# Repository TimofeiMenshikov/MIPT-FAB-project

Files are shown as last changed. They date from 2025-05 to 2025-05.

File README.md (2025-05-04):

# Пояснительная записка к учебному проекту "СТАНЦИЯ МОНИТОРИНГА МИКРОКЛИМАТА" по курсу "Практикум по цифровому производству"

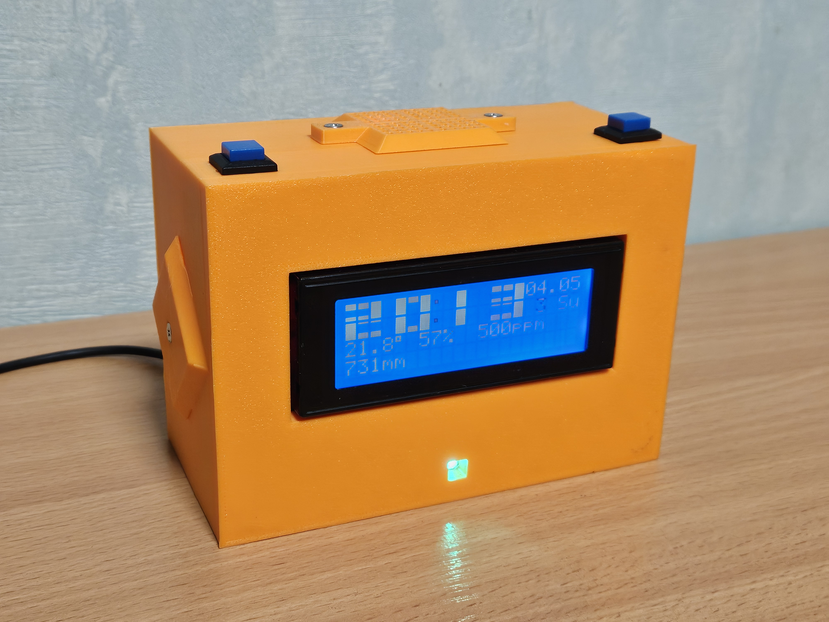
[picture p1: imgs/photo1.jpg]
общее фото станции


## Авторы проекта

- Сапунов Филипп ([@Feanor19](https://t.me/Feanor19)) - проектирование корпуса, пайка, сборка устройства
- Меньшиков Тимофей ([@tifomei](https://t.me/tifomei)) - код прошивки и всё с ним связанное

## Причины выбора темы

В комнате в общежитии понадобилось наблюдать примерный уровень углекислого газа и температуру воздуха, чтобы эффективнее проветривать помещение (особенно в холодное время года).

## Первичные требования к проекту

### Измеряемые показатели

1. Температура окружающего воздуха;
2. Влажность окружающего воздуха;
3. Атмосферное давление;
4. Уровень углекислого газа (ppm).

### Отображаемая информация

1. Время и дата (при отключении питания не должны отставать от реального);
2. Температура, влажность, давление, углекислый газ (показания с датчиков в данный момент времени);
3. Графики показаний с перечисленных выше датчиков за сутки.

### Общие требования

1. Изменение яркости дисплея в соответствии с освещённостью вокруг (когда в комнате выключен свет, дисплей не должен ярко гореть);
2. Светодиод, отражающий регистрируемый уровень углекислого газа (зелёный, когда показания в норме, красный и мигающий красный при превышении нормы);
3. Удобный интерфейс, управляемый несколькими механическими кнопками. Множество режимов отображения, лёгкое переключение между ними. Настройка режима яркости дисплея и светодиода, выставление времени.
4. Питание должно быть возможно от обычного блока питания на 5В (как для смартфона), разъём USB Type-C или micro-USB.

## Первичные поставленные задачи

1. Выбор электронных компонентов
2. Прототипирование на макетной плате, проверка компонентов
3. Составление блок-схемы интерфейса
4. Проектирование схемы соединения компонентов
5. Проектирование моделей корпуса
6. Разработка и тестирование прошивки на макетной плате
7. Сборка и проверка работоспособности

## Процесс решения поставленных задач

Здесь кратко описан процесс решения поставленных задач. Некоторые принятые по началу решения изменялись в дальнейшем; здесь всё представлено в хронологической последовательности. Чтобы узнать финальную версию, см. [здесь](#финальная-версия)

### Выбор электроники (первая версия)

В соответствии с заданными требованиями были подобраны следующие компоненты:

1. Arduino Nano;
2. Датчик температуры, влажности, давления BME280;
3. Датчик углекислого газа MH-Z19B;
4. Большой символьный дисплей LCD 2004 I2C;
5. RTC (часы реального времени) DS3231 mini;
6. Механические кнопки;
7. Фоторезистор;
8. RGB LED модуль;
9. Разъём питания USB Type-C.

### Первая версия блок-схемы интерфейса

В соответствии с заданными требованиями была составлена блок-схема интерфейса с использованием двух кнопок.

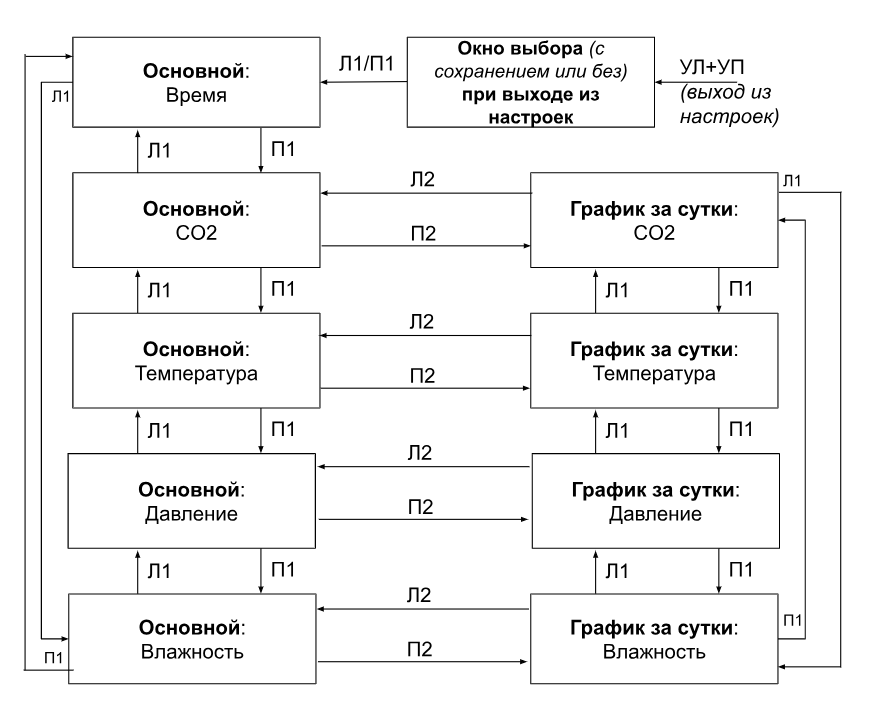
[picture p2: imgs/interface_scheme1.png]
блок-схема интерфейса 1


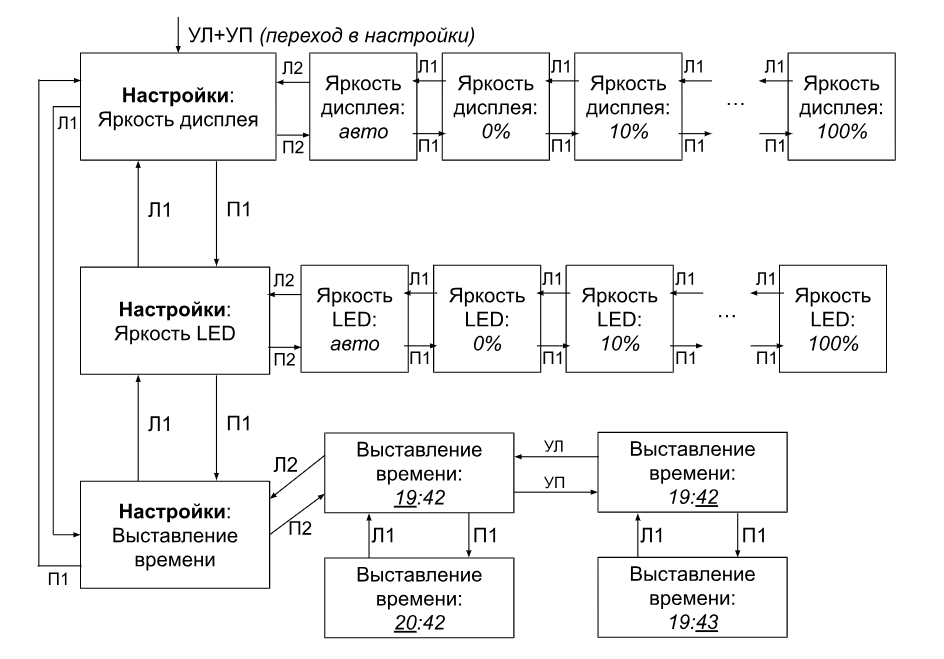
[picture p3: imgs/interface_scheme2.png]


Обозначения:

- Л1 – одиночное нажатие левой кнопки
- П1 – одиночное нажатие правой кнопки
- Л2 – двойное нажатие левой кнопки
- П2 – двойное нажатие правой кнопки
- УЛ – длительное удержание левой кнопки
- УП – длительное удержание правой кнопки

В основном режиме отображается один показатель увеличено, остальные – в уменьшенном и сокращённом виде. УЛ+УП (одновременное длительное нажатие левой и правой кнопки) из любого экрана переводит в режим настроек, и из любого экрана настроек переводит в основной через окно с подтверждением сохранения изменений.

### Прототипирование на макетной плате и начало разработки прошивки

Для отлаживания прошивки в процессе её разработки требовались все компоненты, подключенные к макетной плате (breadboard), и возможность легко подключать/отключать их к разным пинам ардуино. Кроме того, ещё не была утверждена финальная схема соединения компонентов, т.к. во время разработки прошивки могли выясниться какие-то нюансы, требующие её модификации. По этим причинам уже на этом этапе к кнопкам и датчику CO2 были припаяны половинки джамперов папа-папа, чтобы обеспечить их легкое подключение к макетной плате. Джамперов мама-папа на тот момент в наличии не было, а паяльник был ещё горячий, поэтому половинки джамперов папа-папа были заодно припаяны к пинам дисплея (геометрия пинов не позволяла втыкать их в макетную плату напрямую).

В ходе разработки прошивки выяснилось, что отлавливать раздельно события "УЛ" и "УП" при наличии события "УЛ+УП" неоправданно сложно. Поэтому часть интерфейса, отвечающая за выставление времени в настройках, была изменена: переход между выставлением часов и выставлением минут совершается путём срабатывания "П1", а выставление числа часов/минут совершается путём срабатывания "Л1" (число увеличивается на единицу).

### Первая версия схемы соединения компонентов

Через некоторое время после начала разработки прошивки появилось понимание, как должна выглядеть схема соединения компонентов. По итогу была спроектирована и утверждена следующая схема:

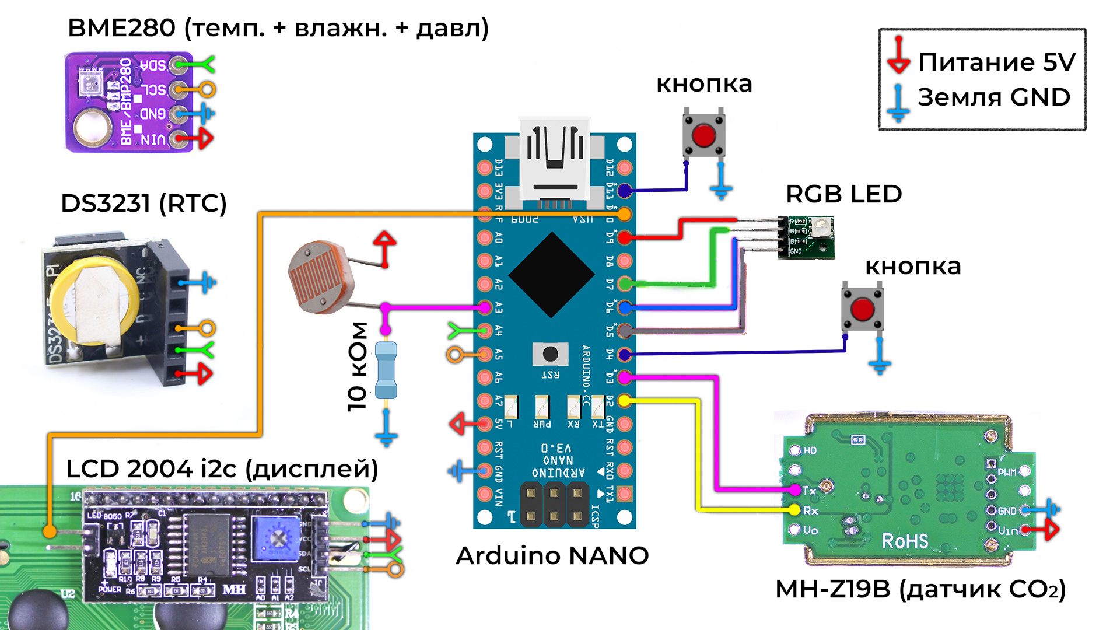
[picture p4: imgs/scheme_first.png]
схема соединения


Датчик BME280, RTC и дисплей подключены на общую шину I2C. На схеме не показан порт питания, в него должен вставляться провод от обычного блока питания на 5В (как для смартфонов).

### Проектирование корпуса

Все файлы были сделаны в SOLIDWORKS 2020, расположены [тут](models/).

Были созданы макеты компонентов (названия начинаются с "mock_") для проверки в виртуальной сборке. Для крепления было решено использовать впаиваемые гайки (aka резьбовые втулки) и винты. Для крепления двух половинок корпуса ([передняя](models/case_front.SLDPRT) и [задняя](models/case_back.SLDPRT)) используются потайные М3 винты (чтобы были вровень с поверхностью, закрывать их какой-то нашлепкой не предполагается). Также М3 винтами, вкручиваемыми снаружи, крепятся датчик BME и разъём питания, закрепляясь изнутри обычной гайкой.

В ходе разработки корпуса и продумывания крепления компонентов выяснилось, что выбранный разъём питания USB Type-C не имеет удобных отверстий для крепления, в отличие от разъёма питания micro-USB из личных запасов, который и был в итоге выбран.

Датчику BME требуется доступ к воздуху в комнате, для этих целей на [задней грани](models/case_back.SLDPRT) предусмотрено квадратное отверстие размером чуть больше чувствительной части датчика.

Датчику CO2 тоже требуется доступ к воздуху в комнате, для этого сделана решётка в виде отдельной [детали](models/case_grid.SLDPRT), накрывающая датчик сверху. К задней половине корпуса она крепится потайными М3 винтами, которые вкручиваются в ответные впаиваемые гайки. Сам датчик помещается на сделанную для него "полочку", фиксирующую его положение по двум осям; соединение половин корпуса фиксирует его положение и по третьей оси.

Под фоторезистор отдельное отверстие не предусмотрено, вместо этого оставлена достаточно широкая щель по краям дисплея, с обратной стороны которой предполагается закреплять фоторезистор (специальное крепление не предусмотрено).

#### Подгонка размеров

Отверстия под впаиваемые гайки должны были быть нужного размера, чтобы те в них хорошо закреплялись. При этом при 3D-печати размеры могут значительно искажаться. Поэтому были созданы тестовые модельки (их названия начинаются с "test_suite"), в которых были сделаны отверстия под М2 и М3 впаиваемые гайки, а также под потайные винты М3, использующиеся в нескольких местах корпуса. Во второй [тестовой модельке](models/test_suite_potay.SLDPRT) заодно была протестирована печать "крепёжного уха" в том же положении, в котором оно печаталось как часть передней половинки корпуса.

Тестовые модельки печатались из PLA, из него же печатались и финальные модели.

Первая тестовая моделька претерпела несколько итераций печати и сверки, пока не был подобран нужный размер.

### Продолжение разработки прошивки

В ходе продолжения разработки прошивки выяснилось, что требуется немного изменить подключение светодиода. Пин G светодиода был подключен в пин ардуино D7, не поддерживающий ШИМ. Из-за этого когда светодиод светился зеленым, его яркостью нельзя было управлять (это было упущено по началу, т.к. проверка изменения яркости проводилась при свечении красным). Модификацию схемы подключения см. [здесь](#финальная-версия)

### Сборка

К моменту, когда было пора паять схему, пришла идея вместо этого собрать все на джамперах, получив таким образом полностью разборную конструкцию, позволяющую легко заменить любой компонент, даже без перепаивания. Для этих целей из найденных в личных запасах "ног" были спаяны 4 шины: земля, питание и две шины для I2C.

Первая собранная и уложенная в корпус схема выглядела так:

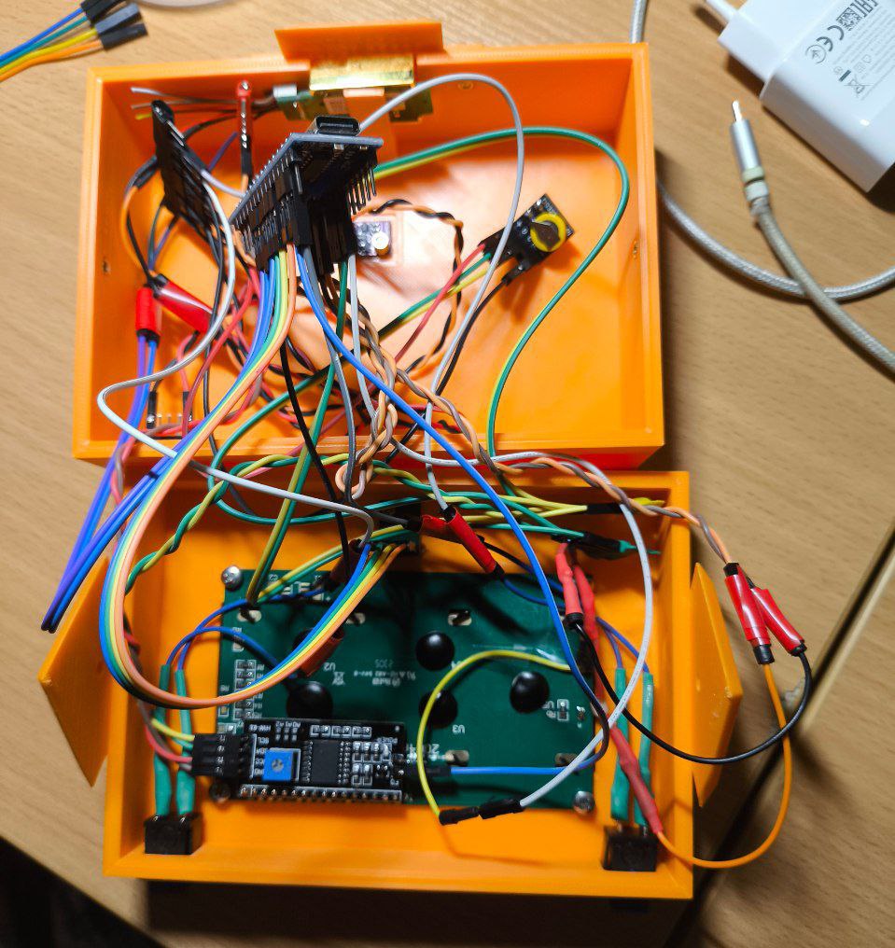
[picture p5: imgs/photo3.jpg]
Первая версия сборки


И она, конечно, не заработала. Только часть компонентов были надежно прикреплены к корпусу (дисплей, RGB LED, датчик BME, датчик CO2), остальные (ардуино, RTC, все четыре шины...) свободно перемещались внутри, вызывая отсоединение одних контактов и появление незапланированных других.

После этого схема была целиком разобрана и собрана заново:

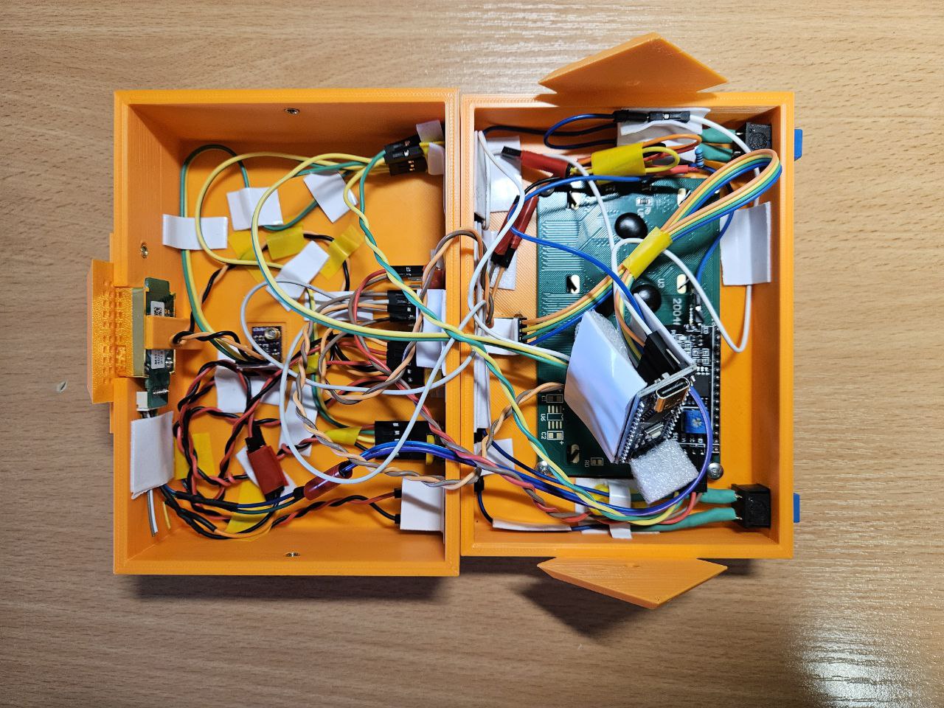
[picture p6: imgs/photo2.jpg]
Вторая версия сборки


На этот раз все провода прикреплялись к стенкам двусторонним скотчем, все соединения прозванивались. Выяснилось, что левая кнопка работала только при определенном положении припаянных к ней проводов, поэтому они тоже были надёжно зафиксированы c помощью подручных средств. Стоит заметить, что обильное использование двустороннего скотча не нарушает разборность конструкции и не мешает при надобности заменять отдельные компоненты, т.к. он снимается без следа.

### Проблемы и их решения после сборки

Казалось бы, станция была собрана и полностью работала, откуда взяться проблемам?

**Проблема №1**:

Один из авторов захотел попробовать запитать станцию от умного блока питания, способного выдавать различные мощности в зависимости от типа подключенного устройства. После этого эксперимента ардуино не работало при питании через внешний порт; вероятно, сгорел стабилизатор питания на входе 5V.

**Решение:**

Была получена новая ардуино и, благодаря разборности схемы, легко и без пайки подключена вместо старой.

**Проблема №2**:

Через некоторое время после использования станции отвалилось гнездо на плате питания.

**Решение:**

К новой такой же плате были припаяны ноги, плата была подключена вместо старой. Разборность схемы снова немного упростила замену сломанных компонентов.

## Финальная версия

### Компоненты

1. Arduino Nano;
2. Датчик температуры, влажности, давления BME280;
3. Датчик углекислого газа MH-Z19B;
4. Большой символьный дисплей LCD 2004 I2C;
5. RTC (часы реального времени) DS3231 mini;
6. Две механические кнопки;
7. Фоторезистор и резистор 10кОм;
8. RGB LED модуль;
9. Разъём питания micro-USB.

_Изменения по сравнению с первой версией:_

Изменён разъём питания из-за отсутствия возможности крепежа первого.

### Схема соединения компонентов

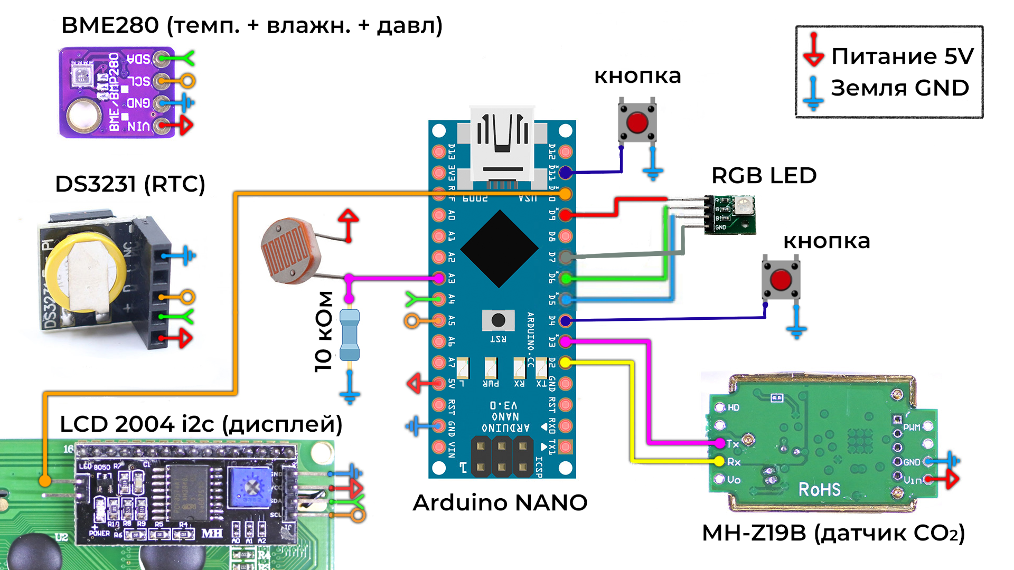
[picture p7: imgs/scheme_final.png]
схема


_Изменения по сравнению с первой версией:_

Изменено подключение пинов светодиодного модуля.

### Блок-схема интерфейса

блок-схема интерфейса 1

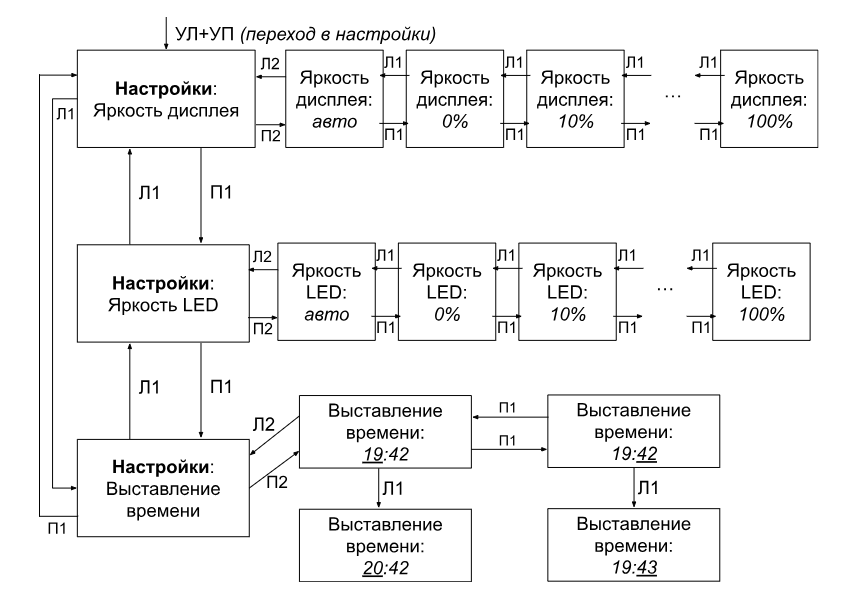
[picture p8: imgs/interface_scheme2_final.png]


_Изменения по сравнению с первой версией:_

Изменена только вторая часть интерфейса: убраны события "УЛ" и "УП", которые использовались только в выставлении времени.

### Модели для 3D-печати

Все модели расположены в директории [models](/models).

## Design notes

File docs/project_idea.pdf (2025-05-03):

Команда: Сапунов Филипп sapunov.fv@phystech.edu, Меньшиков Тимофей

Цель проекта: спроектировать и изготовить компактную станцию, измеряющую несколько параметров воздуха в комнате (температура, влажность, свежесть), уведомляющую о значительном ухудшении качества воздуха и отображающую полученные измерения несколькими удобными способами.

Задачи проекта: выбор доступной элементной базы; написание кода для первого прототипа и сборка схемы на макетной плате; проектирование и изготовление корпуса; доработка кода для увеличения количества режимов отображения и обработки собираемой с датчиков информации; сверка показаний датчиков в течение продолжительного периода времени с коммерческим решением.

Существующие аналоги:

1. Часы-метеостанция на Arduino своими руками - AlexGyver Technologies (https://alexgyver.ru/meteoclock/?ysclid=m6q3mdb4qh222157203) -открытое решение. Имеет несколько небольших недостатков (неудобство управления, слабая защита питания), которые планируется исправить в предлагаемом проекте, помимо дополнения новыми функциями.
2. Монитор качества воздуха с AliExpress (https://aliexpress.ru/item/1005007847792846.html?sku_id=12000042521033746) - один из множества вариантов, наиболее близкий по планируемому функционалу.
3. LIFAair LA352 - Система домашней очистки воздуха (https://lifarussia.ru/product/la352/) - включает в себя, помимо самого устройства очистки, монитор-контроллер качества воздуха. Имеется потенциальная возможность сверить показания этого устройства с результатом проекта (см. последний пункт задач проекта), учитывая при выводах значительную разницу ценовых категорий.

Подробный анализ аналогов будет представлен в итоговом отчете.

Эскиз: (итоговый дизайн может отличаться)

# Предложение проекта: станция мониторинга микроклимата

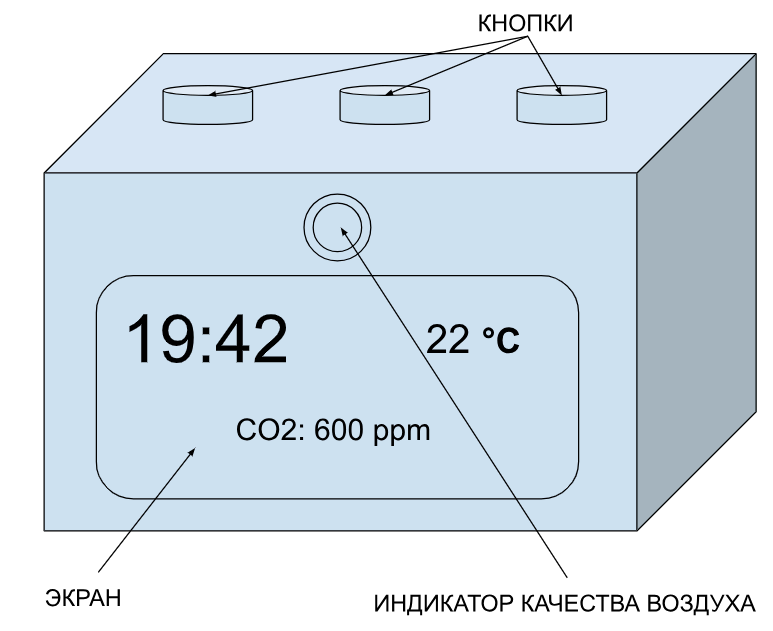
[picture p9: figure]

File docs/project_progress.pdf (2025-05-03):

# ПРЕЗЕНТАЦИЯ ПРОГРЕССА ПО ПРОЕКТУ «СТАНЦИЯ МОНИТОРИНГА МИКРОКЛИМАТА»

I. Были подробно сформулированы и утверждены требования к проекту:
1. Измеряемые показатели:
a. Температура окружающего воздуха (точность ±1 ºC);
b. Влажность окружающего воздуха;
c. Атмосферное давление;
d. Уровень углекислого газа (ppm).
2. Отображаемая информация:
a. Время и дата (при отключении питания не должны отставать от реального);
b. Температура, влажность, давление, углекислый газ (показания с датчиков в данный момент времени);
c. Графики показаний с перечисленных выше датчиков за сутки.
3. Общие требования:
a. Изменение яркости дисплея в соответствии с освещѐнностью вокруг (когда в комнате выключен свет, дисплей не должен ярко гореть);
b. Светодиод, отражающий регистрируемый уровень углекислого газа (зелѐный, когда показания в норме, красный и мигающий красный при превышении нормы);
c. Удобный интерфейс, управляемый несколькими механическими кнопками. Множество режимов отображения, лѐгкое переключение между ними. Настройка режима яркости дисплея и светодиода, выставление времени.
d. Питание должно быть возможно от обычного блока питания на 5В (как для смартфона), разъѐм USB Type-C или micro-USB.

II. В соответствии с заданными требованиями были подобраны следующие компоненты:

1. Arduino Nano;
2. Датчик температуры, влажности, давления BME280;
3. Датчик углекислого газа MH-Z19B;
4. Большой символьный дисплей LCD 2004 I2C;
5. RTC (часы реального времени) DS3231 mini;
6. Механические кнопки (из личных запасов, выбор конкретных позже);
7. Фоторезистор;
8. RGB LED модуль;
9. Разъѐм питания USB Type-C;
10. В личных запасах были макетная плата (breadboard) и набор проводов (jump wire) для сборки прототипа.

III. В соответствии с заданными требованиями был составлен план интерфейса с использованием двух механических кнопок:

- Л1 – одиночное нажатие левой кнопки
- П1 – одиночное нажатие правой кнопки
- Л2 – двойное нажатие левой кнопки
- П2 – двойное нажатие правой кнопки
- УЛ – длительное удержание левой кнопки

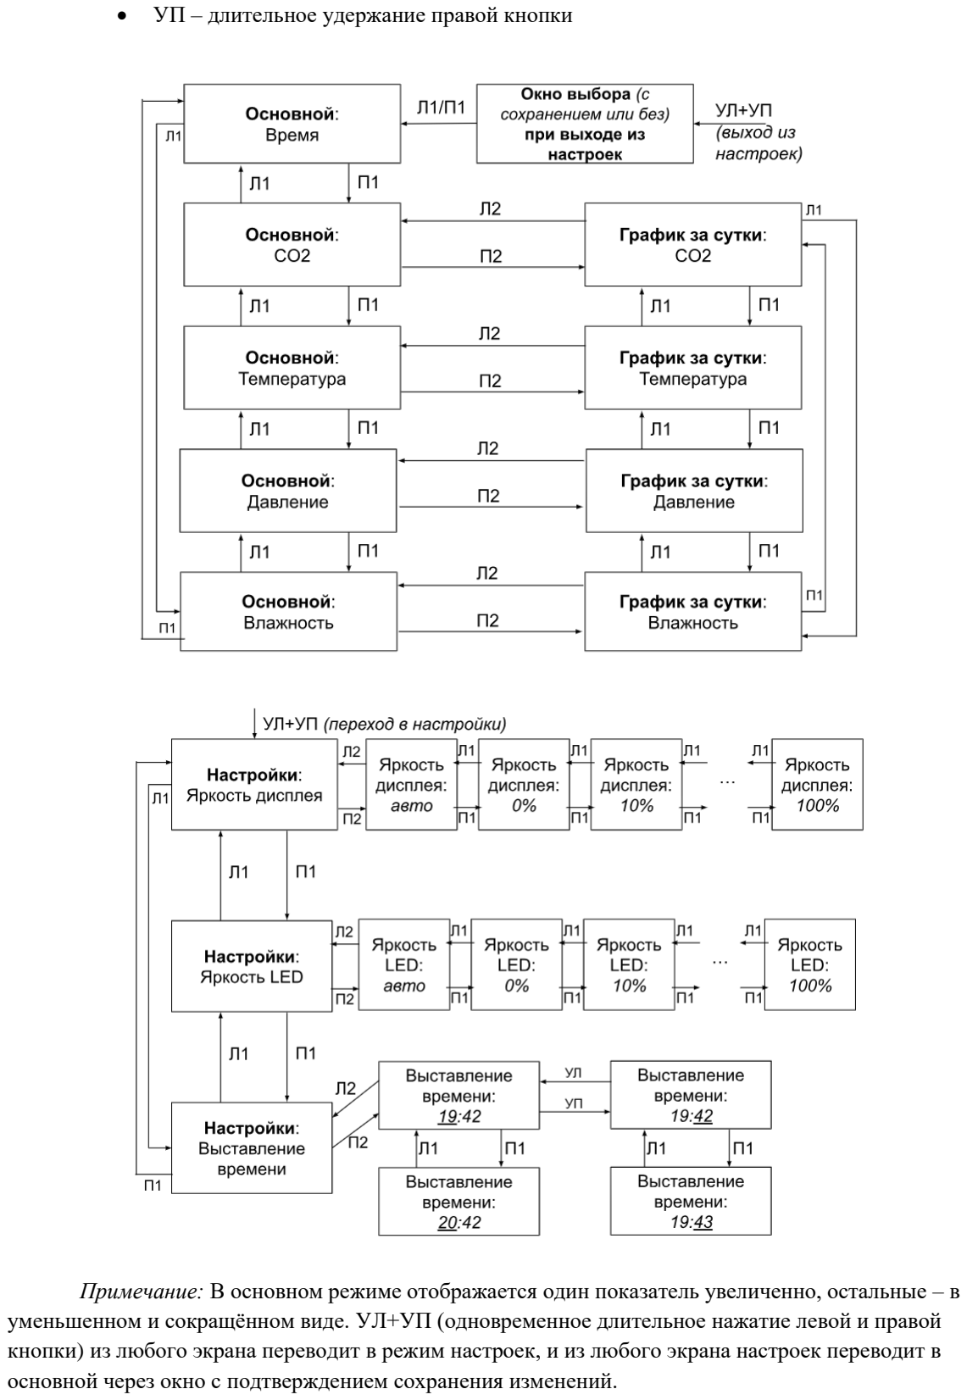
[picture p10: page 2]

- УП – длительное удержание правой кнопки

Примечание: В основном режиме отображается один показатель увеличенно, остальные – в уменьшенном и сокращѐнном виде. УЛ+УП (одновременное длительное нажатие левой и правой кнопки) из любого экрана переводит в режим настроек, и из любого экрана настроек переводит в основной через окно с подтверждением сохранения изменений.

IV. Была спроектирована схема соединения компонентов:

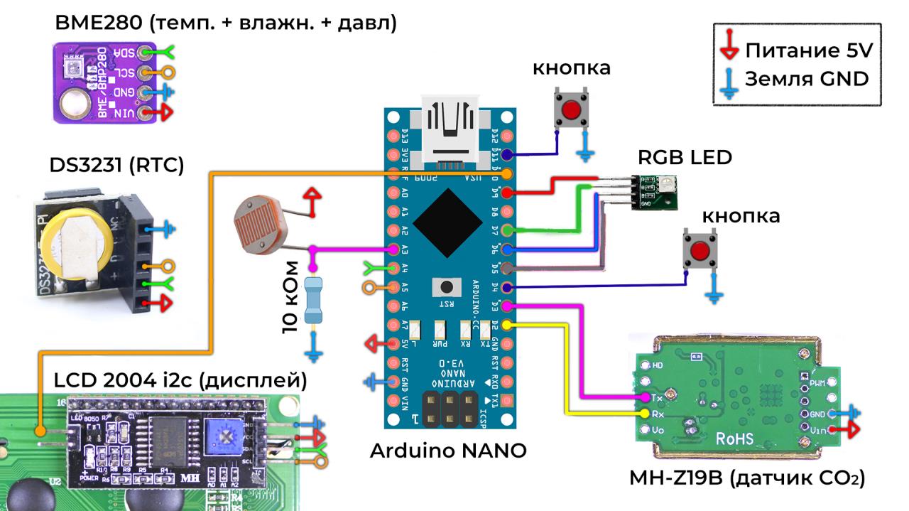
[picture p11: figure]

V. Была проверена работоспособность отдельных компонентов на макетной плате с помощью готовых скетчей из библиотек, предназначенных для работы с этими компонентами.

VI. Что остаѐтся сделать:

1. Разработать модель корпуса;
2. Дописать код прошивки (сейчас в разработке);
3. Спаять схему, заключить в корпус.

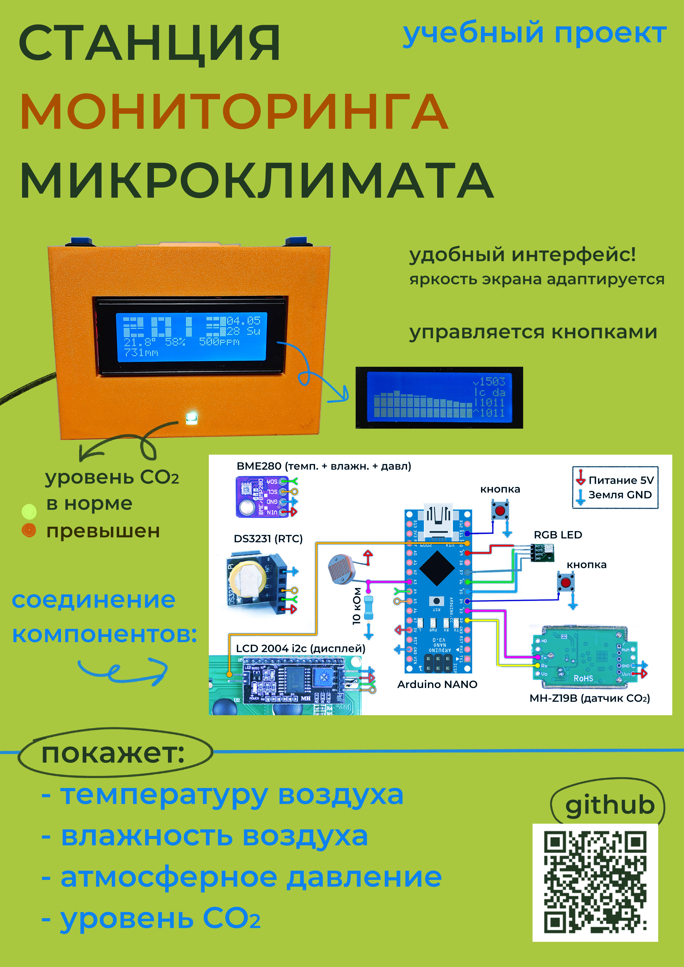
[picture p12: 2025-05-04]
docs/POSTER.png

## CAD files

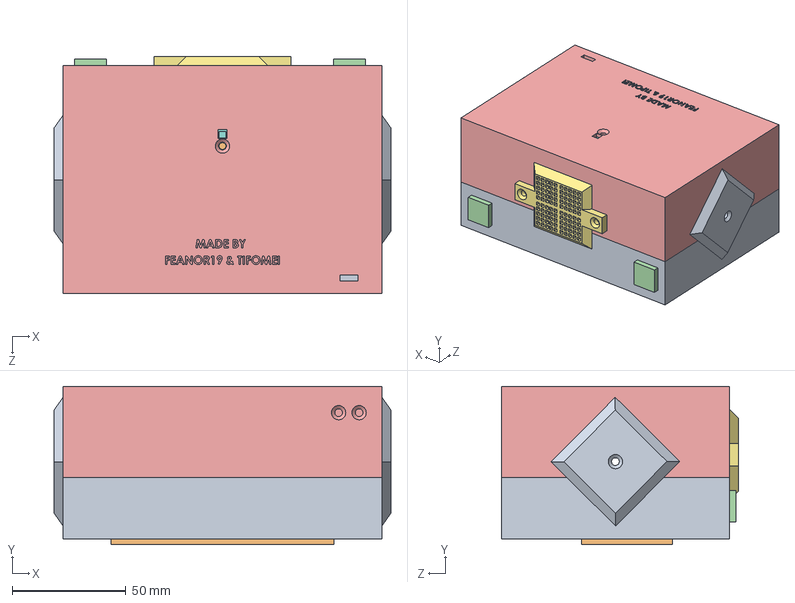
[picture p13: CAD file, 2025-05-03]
models/assemble.SLDASM
148.0 x 69.4 x 104.0 mm
case_front
mock_display
mock_rgb_led
mock_button x 2
case_back
mock_CO2
case_grid
mock_bme

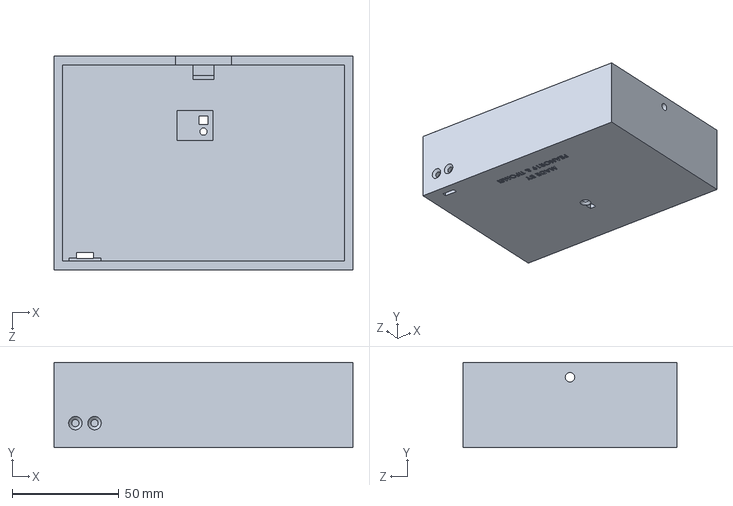
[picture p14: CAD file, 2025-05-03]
models/case_back.SLDPRT
140.0 x 40.0 x 100.0 mm

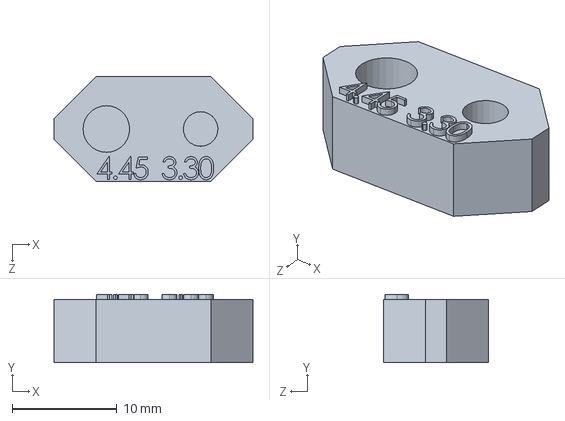
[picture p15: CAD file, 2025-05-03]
models/test_suite_vtulki_4.SLDPRT
19.0 x 6.50 x 10.0 mm

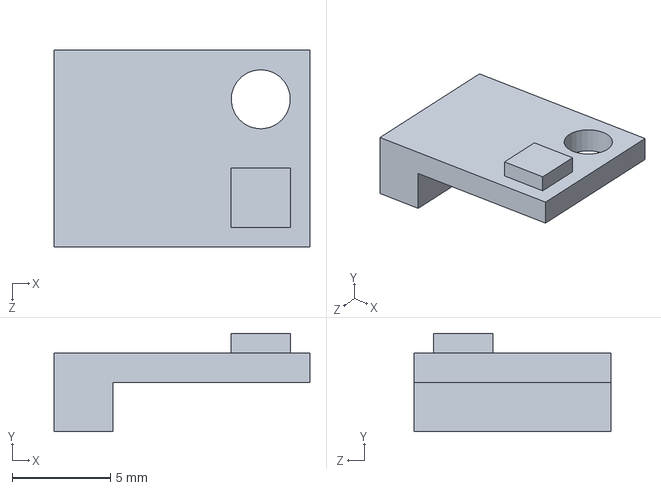
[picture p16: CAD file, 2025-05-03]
models/mock_bme.SLDPRT
13.0 x 5.00 x 10.0 mm

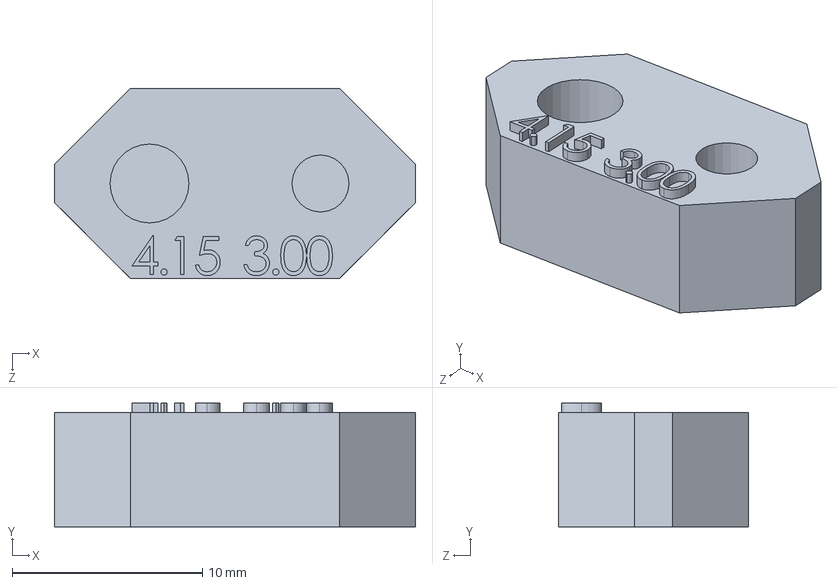
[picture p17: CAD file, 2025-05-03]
models/test_suite_vtulki_2.SLDPRT
19.0 x 6.50 x 10.0 mm

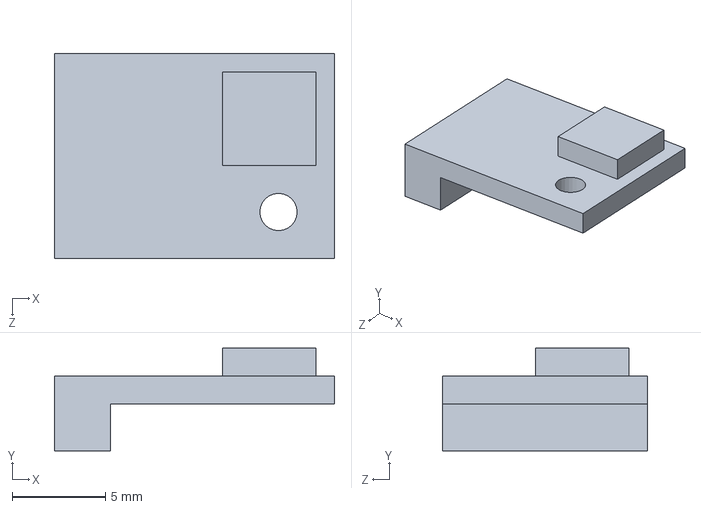
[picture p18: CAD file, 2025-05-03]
models/mock_rgb_led.SLDPRT
15.0 x 5.50 x 11.0 mm

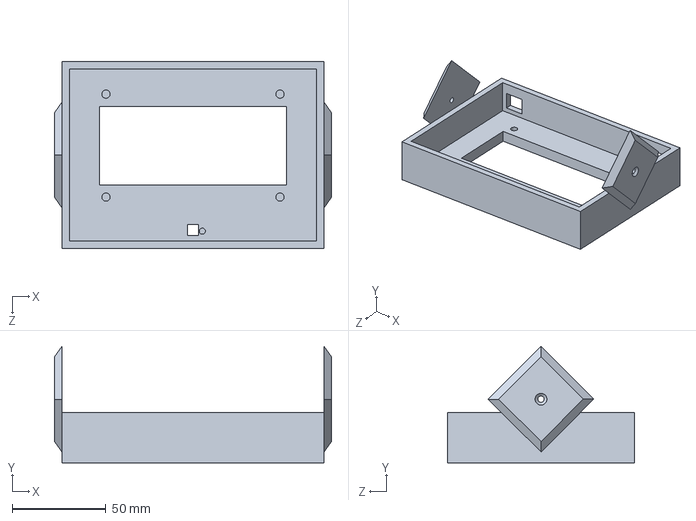
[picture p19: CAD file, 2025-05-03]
models/case_front.SLDPRT
148.0 x 62.3 x 100.0 mm

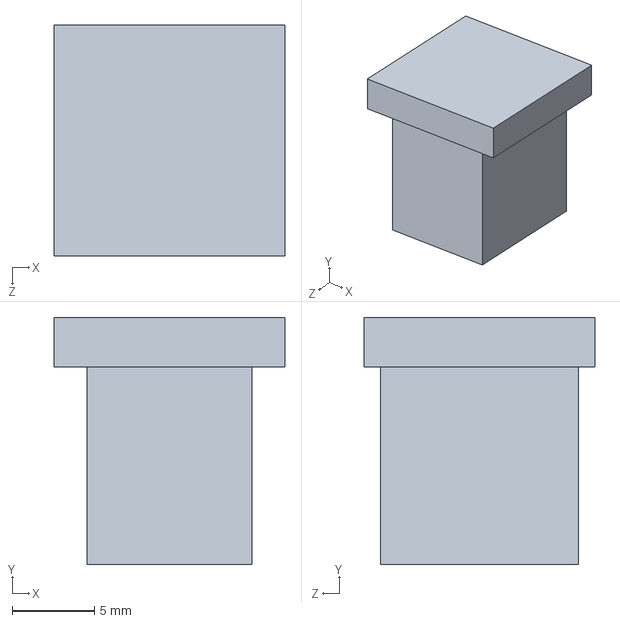
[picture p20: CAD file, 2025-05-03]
models/mock_button.SLDPRT
14.0 x 15.0 x 14.0 mm

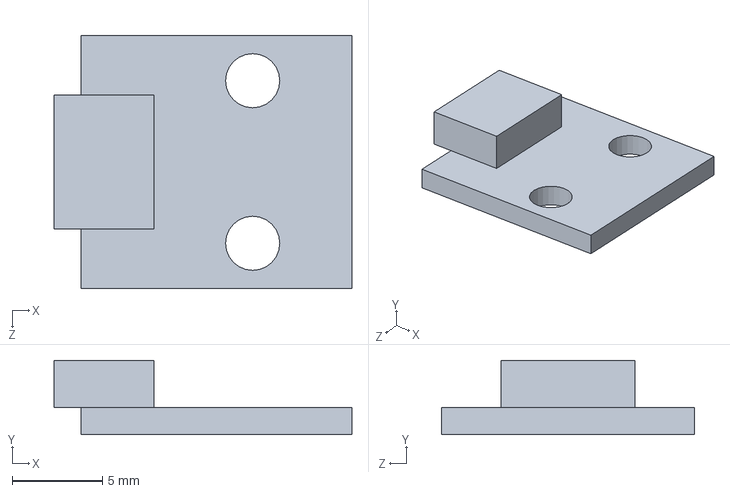
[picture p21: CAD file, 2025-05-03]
models/mock_micro_usb.SLDPRT
16.5 x 4.10 x 14.0 mm

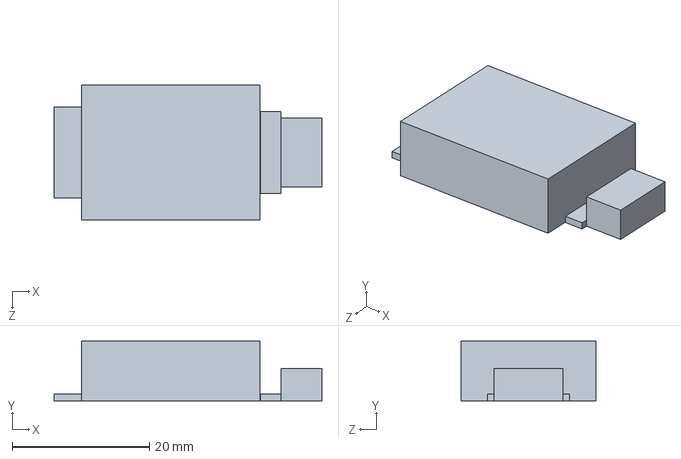
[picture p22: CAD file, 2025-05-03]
models/mock_CO2.SLDPRT
39.0 x 8.70 x 19.7 mm

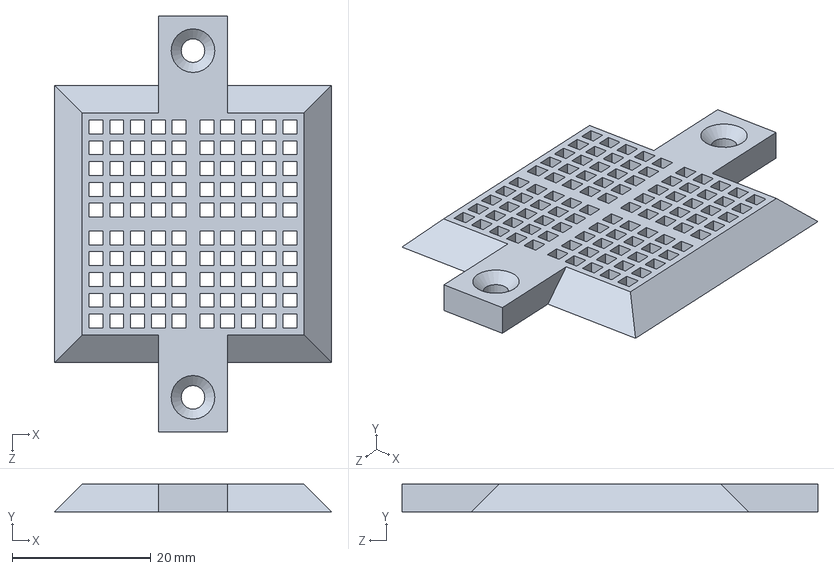
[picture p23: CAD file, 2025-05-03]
models/case_grid.SLDPRT
40.0 x 4.00 x 60.0 mm

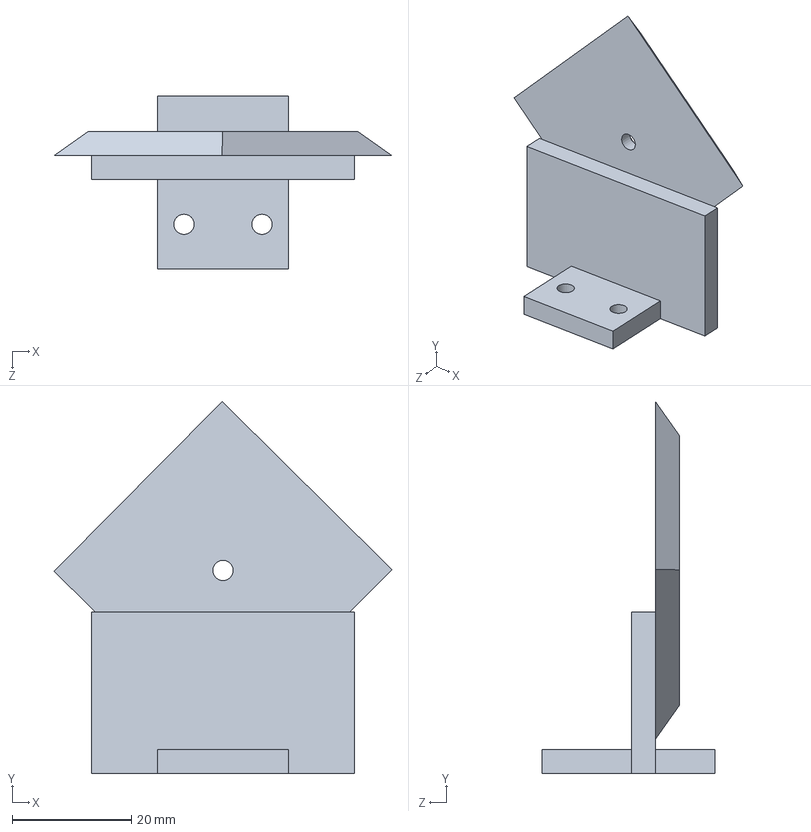
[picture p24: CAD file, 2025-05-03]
models/test_suite_potay.SLDPRT
56.6 x 62.3 x 29.0 mm

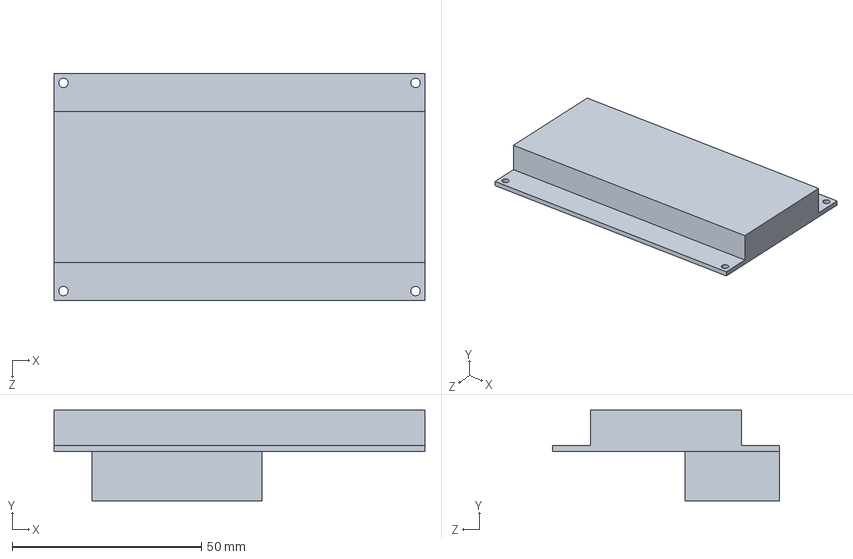
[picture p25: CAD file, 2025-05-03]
models/mock_display.SLDPRT
98.0 x 24.0 x 60.0 mm

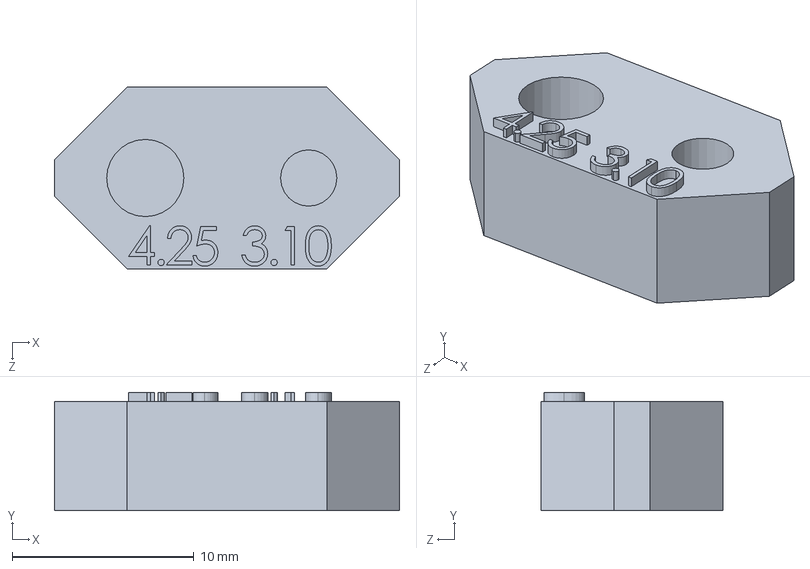
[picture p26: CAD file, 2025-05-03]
models/test_suite_vtulki_3.SLDPRT
19.0 x 6.50 x 10.0 mm

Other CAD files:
models/test_suite_vtulki.SLDPRT
models/case_back_real.SLDPRT

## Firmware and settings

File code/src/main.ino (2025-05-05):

#define RESET_CLOCK 0     // сброс часов на время загрузки прошивки (для модуля с несъёмной батарейкой). Не забудь поставить 0 и прошить ещё раз!
#define SENS_TIME 10000   // время обновления показаний сенсоров на экране, миллисекунд


// управление яркостью
byte LED_BRIGHT = 10;         // при отсутствии сохранения в EEPROM: яркость светодиода СО2 (0 - 10) (коэффициент настраиваемой яркости индикатора по умолчанию, если нет сохранения и не автоматическая регулировка  )
byte LCD_BRIGHT = 10;         // при отсутствии сохранения в EEPROM: яркость экрана (0 - 10) (коэффициент настраиваемой яркости экрана по умолчанию, если нет сохранения и не автоматическая регулировка  )
byte LED_BRIGHT_local = LED_BRIGHT;
byte LCD_BRIGHT_local = LCD_BRIGHT;


#define BRIGHT_THRESHOLD 150  // величина сигнала, ниже которой яркость переключится на минимум (0-1023)
#define LED_BRIGHT_MAX 25    // макс яркость светодиода СО2 (0 - 255)
#define LED_BRIGHT_MIN 1      // мин яркость светодиода СО2 (0 - 255)
#define LCD_BRIGHT_MAX 25    // макс яркость подсветки дисплея (0 - 255)
#define LCD_BRIGHT_MIN 1      // мин яркость подсветки дисплея (0 - 255)


#define PRESSURE 0        // 0 - график давления, 1 - график прогноза дождя (вместо давления). Не забудь поправить пределы графика

#define DISPLAY_ADDR 0x27 // адрес платы дисплея

// пределы для индикатора  
#define maxCO2 1000       // и выше - красный
#define blinkLEDCO2 1500  // Значение СО2, при превышении которого будет мигать индикатор

#include <EEPROM.h>

// пределы отображения для графиков
#define TEMP_MIN 15
#define TEMP_MAX 35
#define HUM_MIN 0
#define HUM_MAX 100
#define PRESS_MIN 720
#define PRESS_MAX 760
#define CO2_MIN 400
#define CO2_MAX 2000

// пины
#define BACKLIGHT 10
#define PHOTO A3

#define MHZ_RX 2
#define MHZ_TX 3

#define LED_COM 7
#define LED_R 9
#define LED_G 6
#define LED_B 5
#define BTN_PIN 11 // D11
#define BTN_PIN2 4 // D4

#define IS_RED    1
#define IS_GREEN  2
#define IS_BLUE   4


// библиотеки
#include <Wire.h>
#include <LiquidCrystal_I2C.h>

LiquidCrystal_I2C lcd(DISPLAY_ADDR, 20, 4);

#include "RTClib.h"
RTC_DS3231 rtc;
DateTime now;

#include <Adafruit_Sensor.h>
#include <Adafruit_BME280.h>

Adafruit_BME280 bme;

#include <MHZ19_uart.h>
MHZ19_uart mhz19;

unsigned long sensorsTimer = SENS_TIME;
unsigned long drawSensorsTimer = SENS_TIME;
unsigned long clockTimer = 500;



unsigned long dayPlotTimer = ((long)1.6 * 60 * 60 * 1000);  // 1.6 часа


unsigned long plotTimer = dayPlotTimer;
unsigned long brightTimer = (2000);

unsigned long sensorsTimerD = 0;
unsigned long drawSensorsTimerD = 0;
unsigned long clockTimerD = 0;

unsigned long dayPlotTimerD = 0;
unsigned long plotTimerD = 0;
unsigned long predictTimerD = 0;
unsigned long brightTimerD = 0;

#include "GyverButton.h"
GButton  button(BTN_PIN,  HIGH_PULL, NORM_CLOSE);
GButton button_back(BTN_PIN2, HIGH_PULL, NORM_OPEN);

int8_t hrs, mins, secs, month, day;
int8_t local_hrs, local_mins;

uint16_t year;
byte mode = 0;
/*
  0 часы и данные
  1 график углекислого за сутки
  2 график влажности за сутки
  3 график температуры за сутки
  4 график давления за сутки
*/

byte podMode = 1; // подрежим меню 
byte mode0scr = 0;

/*  
  0 - Крупно время
  1 - Крупно содержание СО2
  2 - Крупно температура
  3 - Крупно давление
  4 - Крупно влажность
*/

// переменные для вывода
float dispTemp;
byte dispHum;
int dispPres;
int dispCO2 = -1;

// массивы графиков
int tempDay[15];
int humDay[15];
int pressDay[15];
int co2Day[15];

uint32_t pressure_array[6];

/*
  Характеристики датчика BME:
  Температура: от-40 до + 85 °C
  Влажность: 0-100%
  Давление: 300-1100 hPa (225-825 ммРтСт)
  Разрешение:
  Температура: 0,01 °C
  Влажность: 0.008%
  Давление: 0,18 Pa
  Точность:
  Температура: +-1 °C
  Влажность: +-3%
  Давление: +-1 Па
*/

// символы
// график
byte rowS[8] = {0b00000,  0b00000,  0b00000,  0b00000,  0b10001,  0b01010,  0b00100,  0b00000};   // стрелка вниз  
byte row7[8] = {0b00000,  0b11111,  0b11111,  0b11111,  0b11111,  0b11111,  0b11111,  0b11111};
byte row6[8] = {0b00000,  0b00000,  0b11111,  0b11111,  0b11111,  0b11111,  0b11111,  0b11111};
byte row5[8] = {0b00000,  0b00000,  0b00000,  0b11111,  0b11111,  0b11111,  0b11111,  0b11111};  
byte row4[8] = {0b00000,  0b00000,  0b00000,  0b00000,  0b11111,  0b11111,  0b11111,  0b11111};
byte row3[8] = {0b00000,  0b00000,  0b00000,  0b00000,  0b00000,  0b11111,  0b11111,  0b11111};   // в т.ч. для двустрочной цифры 0 
byte row2[8] = {0b00000,  0b00000,  0b00000,  0b00000,  0b00000,  0b00000,  0b11111,  0b11111};   // в т.ч. для двустрочной цифры 4  
byte row1[8] = {0b00000,  0b00000,  0b00000,  0b00000,  0b00000,  0b00000,  0b00000,  0b11111};

// цифры //   
uint8_t UB[8] = {0b11111,  0b11111,  0b11111,  0b00000,  0b00000,  0b00000,  0b00000,  0b00000};   // для двустрочных 7, 0   
uint8_t UMB[8] = {0b11111,  0b11111,  0b11111,  0b00000,  0b00000,  0b00000,  0b11111,  0b11111};  // для двустрочных 2, 3, 5, 6, 8, 9
uint8_t LMB[8] = {0b11111,  0b00000,  0b00000,  0b00000,  0b00000,  0b11111,  0b11111,  0b11111};  // для двустрочных 2, 3, 5, 6, 8, 9
uint8_t LM2[8] = {0b11111,  0b00000,  0b00000,  0b00000,  0b00000,  0b00000,  0b00000,  0b00000};  // для двустрочной 4


uint8_t KU[8] = {0b00000,  0b00000,  0b00000,  0b00001,  0b00010,  0b00100,  0b01000,  0b10000};   // для верхней части %
uint8_t KD[8] = {0b00001,  0b00010,  0b00100,  0b01000,  0b10000,  0b00000,  0b00000,  0b00000};   // для нижней части %


void digSeg(byte x, byte y, byte z1, byte z2, byte z3, byte z4, byte z5, byte z6) {   // отображение двух строк по три символа с указанием кодов символов  
  lcd.setCursor(x, y);
  lcd.write(z1); lcd.write(z2); lcd.write(z3);
  if (x <= 11) lcd.print(" ");
  lcd.setCursor(x, y + 1);
  lcd.write(z4); lcd.write(z5); lcd.write(z6);
  if (x <= 11) lcd.print(" ");
}

void drawDig(byte dig, byte x, byte y) {        // рисуем цифры   
  switch (dig) {            // двухстрочные цифры
    case 0:
      digSeg(x, y, 255, 1, 255, 255, 2, 255);
      break;
    case 1:
      digSeg(x, y, 32, 255, 32, 32, 255, 32);
      break;
    case 2:
      digSeg(x, y, 3, 3, 255, 255, 4, 4);
      break;
    case 3:
      digSeg(x, y, 3, 3, 255, 4, 4, 255);
      break;
    case 4:
      digSeg(x, y, 255, 0, 255, 5, 5, 255);
      break;
    case 5:
      digSeg(x, y, 255, 3, 3, 4, 4, 255);
      break;
    case 6:
      digSeg(x, y, 255, 3, 3, 255, 4, 255);
      break;
    case 7:
      digSeg(x, y, 1, 1, 255, 32, 255, 32);
      break;
    case 8:
      digSeg(x, y, 255, 3, 255, 255, 4, 255);
      break;
    case 9:
      digSeg(x, y, 255, 3, 255, 4, 4, 255);
      break;
    case 10:
      digSeg(x, y, 32, 32, 32, 32, 32, 32);
      break;
  } 
}

void drawPPM(int dispCO2, byte x, byte y) {     // Уровень СО2 крупно на главном экране   ----------------------------
  if (dispCO2 / 1000 == 0) drawDig(10, x, y);
  else drawDig(dispCO2 / 1000, x, y);
  drawDig((dispCO2 % 1000) / 100, x + 4, y);
  drawDig((dispCO2 % 100) / 10, x + 8, y);
  drawDig(dispCO2 % 10 , x + 12, y);
  lcd.setCursor(15, 0);

  lcd.print("ppm");
}

void drawPres(int dispPres, byte x, byte y) {   // Давление крупно на главном экране   ----------------------------
  drawDig((dispPres % 1000) / 100, x , y);
  drawDig((dispPres % 100) / 10, x + 4, y);
  drawDig(dispPres % 10 , x + 8, y);
  lcd.setCursor(x + 11, 1);
  
  lcd.print("mm");
}


void drawTemp(float dispTemp, byte x, byte y) { // Температура крупно на главном экране   ----------------------------
  if (dispTemp / 10 == 0) drawDig(10, x, y);
  else drawDig(dispTemp / 10, x, y);
  drawDig(int(dispTemp) % 10, x + 4, y);
  drawDig(int(dispTemp * 10.0) % 10, x + 9, y);

  lcd.setCursor(x + 7, y + 1);
  lcd.write(0B10100001);    // десятичная точка

  lcd.setCursor(x + 13, y);
  lcd.write(223);             // градусы
}

void drawHum(int dispHum, byte x, byte y) {   // Влажность крупно на главном экране   ----------------------------
  if (dispHum / 100 == 0) drawDig(10, x, y);
  else drawDig(dispHum / 100, x, y);
  if ((dispHum % 100) / 10 == 0) drawDig(0, x + 4, y);
  else drawDig(dispHum / 10, x + 4, y);
  drawDig(int(dispHum) % 10, x + 8, y);
  
  lcd.setCursor(x + 12, y + 1);
  lcd.print("%");
}

void drawClock(byte hours, byte minutes, byte x, byte y) {    // рисуем время крупными цифрами -------------------------------------------
  if (hours > 23 || minutes > 59) return;
  if (hours / 10 == 0) drawDig(10, x, y);
  else drawDig(hours / 10, x, y);
  drawDig(hours % 10, x + 4, y);
  drawDig(minutes / 10, x + 8, y);
  drawDig(minutes % 10, x + 12, y);
}


static const char *dayNames[]  = {
  "Su",
  "Mo",
  "Tu",
  "We",
  "Th",
  "Fr",
  "Sa",
};


void drawData() {                     // выводим дату -------------------------------------------------------------
  int Y = 0;
  if (mode0scr == 1) Y = 2;
              
  lcd.setCursor(15, 0 + Y);
  if (now.day() < 10) lcd.print(0);
  lcd.print(now.day());
  lcd.print(".");
  if (now.month() < 10) lcd.print(0);
  lcd.print(now.month());


  loadClock();              // принудительно обновляем знаки, т.к. возможно необновление знаков в днях недели  
  lcd.setCursor(18, 1);
  int dayofweek = now.dayOfTheWeek();
  lcd.print(dayNames[dayofweek]);
}


void drawPlot(byte pos, byte row, byte width, byte height, int min_val, int max_val, int *plot_array, String label1, String label2, int stretch) {  // график ---------------------------------
  int max_value = -32000;
  int min_value = 32000;

  for (byte i = 0; i < 15; i++) {
    max_value = max(plot_array[i] , max_value);
    min_value = min(plot_array[i] , min_value);
  }

  //рисуем указатель пределов (стрелочки вверх-вниз)  
  lcd.setCursor(15, 0);

  lcd.write(0);
  lcd.setCursor(15, 3);
  lcd.write(0b01011110);

  if (min_val >= max_val) max_val = min_val + 1;

  lcd.setCursor(15, 1); lcd.write(0b01111100);
  lcd.setCursor(15, 2); lcd.write(0b01111100);

  lcd.setCursor(16, 0); lcd.print(max_value);
  lcd.setCursor(16, 1); lcd.print(label1); lcd.print(label2);
  lcd.setCursor(16, 2); lcd.print(plot_array[14]);
  lcd.setCursor(16, 3); lcd.print(min_value);

  for (byte i = 0; i < width; i++) {                  // каждый столбец параметров
    int fill_val = plot_array[i];
    fill_val = constrain(fill_val, min_val, max_val);
    byte infill, fract;
    // найти количество целых блоков с учётом минимума и максимума для отображения на графике
    if ((plot_array[i]) > min_val)
      infill = floor((float)(plot_array[i] - min_val) / (max_val - min_val) * height * 10);
    else infill = 0;
    fract = (float)(infill % 10) * 8 / 10;            // найти количество оставшихся полосок
    infill = infill / 10;

    for (byte n = 0; n < height; n++) {     // для всех строк графика
      if (n < infill && infill > 0) {       // пока мы ниже уровня
        lcd.setCursor(i, (row - n));        // заполняем полными ячейками
        lcd.write(255);
      }
      if (n >= infill) {                    // если достигли уровня
        lcd.setCursor(i, (row - n));
        if (n == 0 && fract == 0) fract++;      // если нижний перел графика имеет минимальное значение, то рисуем одну полоску, чтобы не было пропусков  
        if (fract > 0) lcd.write(fract);        // заполняем дробные ячейки
        else lcd.write(16);                     // если дробные == 0, заливаем пустой
        for (byte k = n + 1; k < height; k++) { // всё что сверху заливаем пустыми
          lcd.setCursor(i, (row - k));
          lcd.write(16);
        }
        break;
      }
    }
  }
}

void loadClock() {
  lcd.createChar(0, row2);
  lcd.createChar(1, UB);
  lcd.createChar(2, row3);
  lcd.createChar(3, UMB);
  lcd.createChar(4, LMB);
  lcd.createChar(5, LM2);
}

void loadPlot() {
  lcd.createChar(0, rowS);      // Стрелка вниз для индикатора пределов  
  lcd.createChar(1, row1);
  lcd.createChar(2, row2);
  lcd.createChar(3, row3);
  lcd.createChar(4, row4);
  lcd.createChar(5, row5);
  lcd.createChar(6, row6);
  lcd.createChar(7, row7);
}


byte LED_ON = (LED_BRIGHT_MAX);
byte LED_OFF = (0);


void setLEDcolor(byte color) {                    // цвет индикатора задается двумя битами на каждый цвет  
  analogWrite(LED_R, LED_ON *  (color == IS_RED));
  analogWrite(LED_G, LED_ON *  (color == IS_GREEN));
  analogWrite(LED_B, LED_ON *  (color == IS_BLUE));
}

void setLED() {
  if (LED_BRIGHT_local < 11) {                                     // если ручные установки яркости
    LED_ON = 255 / 100 *  LED_BRIGHT_local * LED_BRIGHT_local;
  } else {
    checkBrightness();
  }
  
  // ниже задается цвет индикатора в зависимости от показаний датчика CO2: красный, зеленый

  if (dispCO2 >= maxCO2) setLEDcolor(IS_RED);   // красный
  else setLEDcolor(IS_GREEN);    // зеленый
}

void setup() {
  Serial.begin(9600);

  pinMode(BACKLIGHT, OUTPUT);
  pinMode(LED_COM, OUTPUT);
  pinMode(LED_R, OUTPUT);
  pinMode(LED_G, OUTPUT);
  pinMode(LED_B, OUTPUT);
  setLEDcolor(0);

  digitalWrite(LED_COM, 0);
  analogWrite(BACKLIGHT, LCD_BRIGHT_MAX);

  if (EEPROM.read(0) == 122) {      // если было сохранение настроек, то восстанавливаем их  
    mode0scr = EEPROM.read(6);
    LED_BRIGHT = EEPROM.read(8);
    LCD_BRIGHT = EEPROM.read(9);  
    LED_BRIGHT_local = LED_BRIGHT;
    LCD_BRIGHT_local = LCD_BRIGHT;
  }

  lcd.init();
  lcd.backlight();
  lcd.clear();

  mhz19.begin(MHZ_RX, MHZ_TX);
  mhz19.setAutoCalibration(false);

  rtc.begin();
  bme.begin(&Wire);


  bme.setSampling(Adafruit_BME280::MODE_FORCED,
                  Adafruit_BME280::SAMPLING_X1, // temperature
                  Adafruit_BME280::SAMPLING_X1, // pressure
                  Adafruit_BME280::SAMPLING_X1, // humidity
                  Adafruit_BME280::FILTER_OFF);

  if (RESET_CLOCK || rtc.lostPower())
    rtc.adjust(DateTime(F(__DATE__), F(__TIME__)));
  lcd.clear();
  now = rtc.now();


  secs = now.second();  
  mins = now.minute();
  hrs  = now.hour();

  local_hrs = hrs; 
  local_mins = mins;


  bme.takeForcedMeasurement();
  uint32_t Pressure = bme.readPressure();
  for (byte i = 0; i < 6; i++) {          // счётчик от 0 до 5
    pressure_array[i] = Pressure; // забить весь массив текущим давлением    
  }


  // заполняем графики текущим значением
  readSensors();
  for (byte i = 0; i < 15; i++) {   // счётчик от 0 до 14
    tempDay[i] = dispTemp;
    humDay[i] = dispHum;
    if (PRESSURE) {
      pressDay[i] = 0;
    } else {
      pressDay[i] = dispPres;
    }
  }

  drawData();
  loadClock();
  drawSensors();
}

void loop() {
  if (testTimer(brightTimerD, brightTimer)) checkBrightness();  // яркость
  if (testTimer(sensorsTimerD, sensorsTimer)) readSensors();    // читаем показания датчиков с периодом SENS_TIME

  if (testTimer(clockTimerD, clockTimer)) clockTick();          // два раза в секунду пересчитываем время и мигаем точками
  plotSensorsTick();                                // тут внутри несколько таймеров для пересчёта графиков 
  modesTick();                                      // тут ловим нажатия на кнопку и переключаем режимы
  if (mode == 0) {                                  // в режиме "главного экрана"
    if (testTimer(drawSensorsTimerD, drawSensorsTimer)) drawSensors();  // обновляем показания датчиков на дисплее с периодом SENS_TIME
  } else {                                          // в любом из графиков
    if (testTimer(plotTimerD, plotTimer)) redrawPlot();  // перерисовываем график
  }
}

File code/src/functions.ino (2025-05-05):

void checkBrightness() {
  Serial.println(analogRead(PHOTO));
  if (LCD_BRIGHT_local == 11) {                         // если установлен автоматический режим для экрана  
    if (analogRead(PHOTO) < BRIGHT_THRESHOLD) {   // если темно
      analogWrite(BACKLIGHT, LCD_BRIGHT_MIN);
    } else {                                      // если светло
      analogWrite(BACKLIGHT, LCD_BRIGHT_MAX);
    }
  } else {
    analogWrite(BACKLIGHT, LCD_BRIGHT_local * LCD_BRIGHT_local * 2.5);
  }

  if (LED_BRIGHT_local == 11) {                         // если установлен автоматический режим для индикатора  
    if (analogRead(PHOTO) < BRIGHT_THRESHOLD) {   // если темно
      LED_ON = (LED_BRIGHT_MIN);

    } else {                                      // если светло
      LED_ON = (LED_BRIGHT_MAX);
    }
  }
}

/*
  mode:
  0 - Главный экран (Время, CO2, Влажность, Температура)
  1-3 - Графики: СО2, Влажность, Температура
  252 - настройка времени
  253 - настройка яркости экрана (podMode от 0 до 11: выбор от 0% до 100% или автоматическое регулирование)
  254 - настройка яркости индикатора (podMode от 0 до 11: выбор от 0% до 100% или автоматическое регулирование)
  255 - главное меню (podMode от 1 до 3: 1 - Ярк.индикатора, 2 - Ярк.экрана, 3 - Изменение времени)                              
*/

byte last_mode = 0;
byte last_podMode = 0;
byte last_mode0scr = 0;


void modesTick() {
  // отладка перемещения по окнам 
  if (last_mode != mode || last_podMode != podMode || last_mode0scr != mode0scr) {
    Serial.print("mode ");
    Serial.println(mode);
    
    Serial.print("podMode ");
    Serial.println(podMode);

    Serial.print("mode0scr ");
    Serial.println(mode0scr);

    last_mode = mode;
    last_podMode = podMode;
    last_mode0scr = mode0scr;
  }

  button.tick();
  button_back.tick();
  boolean changeFlag = false;
  if (button.isSingle()) {    // одинарное нажатие на кнопку
    Serial.println("Single button");
    
    if (mode >= 240) {
      podMode++;
      switch (mode) {

        case 252:
          if (podMode > 1) podMode = 0;
          changeFlag = true;
          break;

        case 253:             // Перебираем все варианты яркости LCD экрана  
          if (podMode > 11) podMode = 0;
          LCD_BRIGHT_local = podMode;
          checkBrightness();
          changeFlag = true;
          break;

        case 254:             // Перебираем все варианты яркости LED индикатора  
          if (podMode > 11) podMode = 0;
          LED_BRIGHT_local = podMode;
          changeFlag = true;
          break;

        case 255:             // Перебираем все варианты основных настроек  
          if (podMode > 3) podMode = 1;
          changeFlag = true;
          break;
      }
    } else if (mode == 0)  {
      mode0scr++;
        
      if (mode0scr > 4) mode0scr = 0;         // Переключение режима работы главного экрана  
       
      changeFlag = true;
    } else if (mode > 0 && mode < 100) {
      mode++;

      if (mode > 4) mode = 1;

      changeFlag = true;
    } else if (mode == 100) {    // выход с сохранением
      Serial.println("Saving...");
      mode = 0;
      podMode = 0;
      mode0scr = 0;
      changeFlag = true;

      LED_BRIGHT = LED_BRIGHT_local;
      LCD_BRIGHT = LCD_BRIGHT_local;

      if (EEPROM.read(6) != mode0scr) EEPROM.write(6, mode0scr);
      if (EEPROM.read(8) != LED_BRIGHT) EEPROM.write(8, LED_BRIGHT);
      if (EEPROM.read(9) != LCD_BRIGHT) EEPROM.write(9, LCD_BRIGHT);
      if (EEPROM.read(0) != 122) EEPROM.write(0, 122);

      now   = rtc.now();
      secs  = now.second();
      mins  = local_mins;
      hrs   = local_hrs;
      month = now.month();
      year  = now.year();
      day   = now.day();
      rtc.adjust(DateTime(year, month, day, hrs, mins, secs));
      now = rtc.now();
      secs  = now.second();
      month = now.month();
      year  = now.year();
      day   = now.day();
      hrs   = now.hour();
      mins  = now.minute();
    }  
  }

  if (button_back.isSingle()) {    // одинарное нажатие на кнопку
    Serial.println("Single button_back");
    if (mode >= 253) {

      switch (mode) {
        case 253:             // Перебираем все варианты яркости LCD экрана  
          if (podMode == 0)  podMode = 11;
          else               podMode--;
          LCD_BRIGHT_local = podMode;
          checkBrightness();
          changeFlag = true;
          break;

        case 254:             // Перебираем все варианты яркости LED индикатора  
          if (podMode == 0)  podMode = 11;
          else               podMode--;
          LED_BRIGHT_local = podMode;
          changeFlag = true;
          break;

        case 255:             // Перебираем все варианты основных настроек  
          podMode--;
          if (podMode <= 0) podMode = 3;
          changeFlag = true;    
          break;
      }
    }
    else if (mode == 0)
    {
      if (mode0scr <= 0)  mode0scr = 4;
      else                mode0scr--;
      changeFlag = true;
    }
    else if (mode < 100)
    {
      mode--;
      if (mode == 0) mode = 4;
      changeFlag = true;
    }
    else if (mode == 100)
    {
      mode = 0;
      podMode = 0;
      mode0scr = 0;
      changeFlag = true;
      local_hrs = hrs;
      local_mins = mins;
      LED_BRIGHT_local = LED_BRIGHT;
      LCD_BRIGHT_local = LCD_BRIGHT;
    }
    else if (mode == 252)
    {
      if (podMode == 0) {
        local_hrs++;
        if (hrs >= 24) hrs = 0;     
      } else {
        local_mins++;
        if (mins >= 60) mins = 0;
      }
      
      changeFlag = true;
    }
  }

  if (button.isDouble()) {                    // двойное нажатие   ----------------------------
    Serial.println("Double button");

    switch (mode) {

      case 0:
        mode = mode0scr;
        changeFlag = true;
        break;

      case 255:       // главное меню
        if (podMode <= 3) mode = 255 - podMode;   // если настройки яркостей, то переключаемся в настройки пункта меню   

        if (mode == 254) podMode = LED_BRIGHT_local;  // если выбрана яркость LED - устанавливаем текущее показание  
        if (mode == 253) podMode = LCD_BRIGHT_local;  // если выбрана яркость LCD - устанавливаем текущее показание  
        if (mode == 252) podMode = 0;
        changeFlag = true;
        break;
    }
  }

  if (button_back.isDouble()) // двойное нажатие 
  {
    Serial.println("Double button_back");
    if (mode < 100) 
    {
      mode0scr   = mode;
      mode       = 0;
      changeFlag = true;
    }

    switch (mode)
    {
      case 252:
        mode = 255;
        podMode = 3;
        changeFlag = true;
        break;
      case 253:       // ярк. экрана
        mode = 255;
        podMode = 2;
        changeFlag = true;
        break;
      case 254:       // ярк. индикатора
        mode = 255;
        podMode = 1;
        changeFlag = true;
        break;
    }    
  }
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
